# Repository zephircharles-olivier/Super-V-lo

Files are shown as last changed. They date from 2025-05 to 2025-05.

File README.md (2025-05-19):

C’est en combinant passion pour le cyclisme et intérêt pour les systèmes embarqués que j’ai imaginé le Super Vélo : un projet de fin d’année visant à transformer un vélo traditionnel en un moyen de transport intelligent, pratique et connecté.

Le Super Vélo, comme son nom l’indique, regroupe une série d’améliorations techniques soigneusement intégrées. Éclairage avant, feux de signalisation, et collecte de données en temps réel ne sont que quelques-unes des fonctionnalités que j’ai développées pour améliorer la sécurité et l’expérience utilisateur. Grâce à une connexion Internet, les données de vitesse et de fréquence cardiaque sont transmises sur une base de données et consultables directement sur un téléphone cellulaire.

Vous pouvez trouvez içi le code source, les schémas électroniques, les fichiers Gerbers et les fichiers de conception

Voir le projet sur mon site Web: https://tgemaisonneuve.com/wp-admin/post.php?post=1706&action=edit

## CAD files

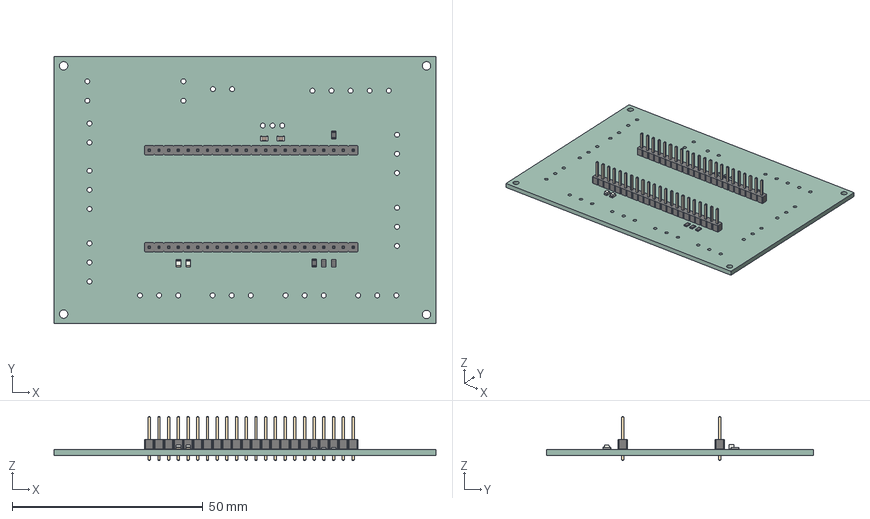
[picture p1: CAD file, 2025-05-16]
Controleur/pcbmaster/pcbmaster/pcbmaster.step
100.0 x 70.0 x 11.5 mm
LED_0805_2012Metric x 2
PinHeader_1x22_P254mm_Vertical x 2
C_0805_2012Metric x 2
R_0805_2012Metric x 4
pcbmaster_PCB

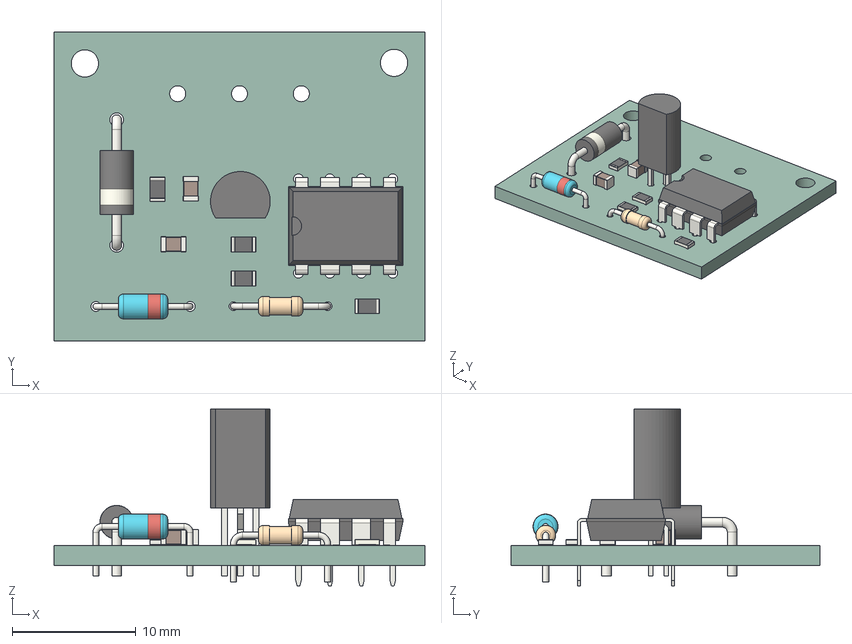
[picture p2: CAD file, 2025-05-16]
Hall_PCB/pcb3/pcb3.step
30.0 x 25.0 x 14.3 mm
R_Axial_DIN0204_L36mm_D16mm_P762mm_Horizontal
D_DO-35_SOD27_P7.62mm_Horizontal
D_DO-41_SOD81_P10.16mm_Horizontal
TO-92L_Narrow
DIP-8_W7.62mm
R_0805_2012Metric x 4
C_0805_2012Metric x 2
pcb3_PCB

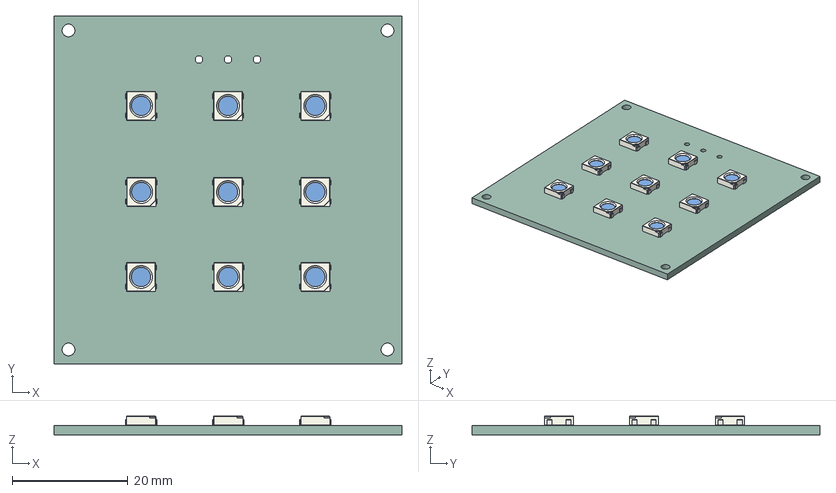
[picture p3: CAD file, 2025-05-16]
Panneaux_LEDs_PCB/pcb2/pcb2.step
60.0 x 60.0 x 3.25 mm
LED_WS2812B_PLCC4_50x50mm_P32mm x 9
pcb2_PCB

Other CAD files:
Boitiers et Assemblage/Magnet1 v28.f3z
Boitiers et Assemblage/PCBMaster Boitier.f3z
Boitiers et Assemblage/Phare Avant.f3z
Boitiers et Assemblage/Phares Arriere.f3z
Boitiers et Assemblage/Switch Boitier.f3d
Panneaux_LEDs_PCB/pcb2/pcb2 Copy v1.f3d

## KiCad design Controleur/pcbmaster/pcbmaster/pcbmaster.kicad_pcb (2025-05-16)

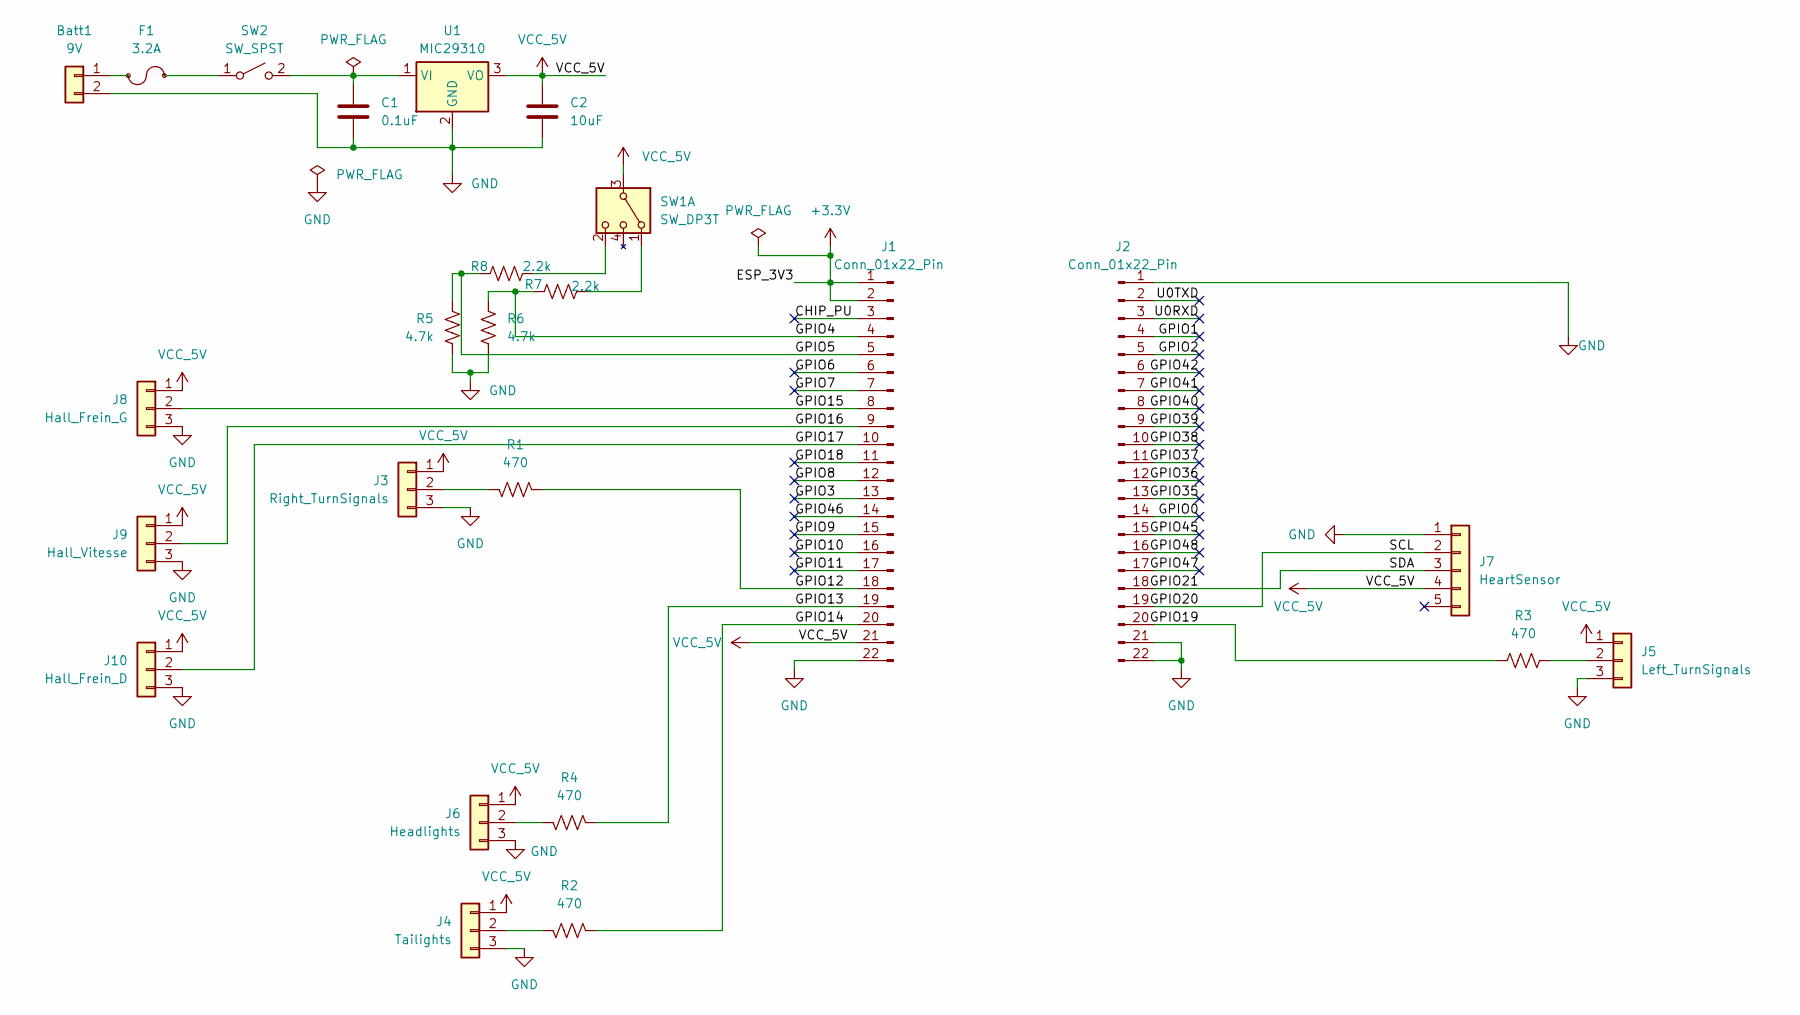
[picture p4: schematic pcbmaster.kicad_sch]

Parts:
Batt1: 9V; 691137710002
C1: 0.1uF; C_0805_2012Metric_Pad1.18x1.45mm_HandSolder
C2: 10uF; C_0805_2012Metric_Pad1.18x1.45mm_HandSolder
F1: 3.2A; FUSE_3519
J1, J2: Conn_01x22_Pin; PinHeader_1x22_P2.54mm_Vertical
J3: Right_TurnSignals; CONN_3pos_GREEN
J4: Tailights; CONN_3pos_GREEN
J5: Left_TurnSignals; CONN_3pos_GREEN
J6: Headlights; CONN_3pos_GREEN
J7: HeartSensor; CONN_5_pos_GREEN
J8: Hall_Frein_G; CONN_3pos_GREEN
J9: Hall_Vitesse; CONN_3pos_GREEN
J10: Hall_Frein_D; CONN_3pos_GREEN
R1, R2, R3, R4: 470; R_0805_2012Metric_Pad1.20x1.40mm_HandSolder
R5, R6: 4.7k; LED_0805_2012Metric_Pad1.15x1.40mm_HandSolder
R7, R8: 2.2k; LED_0805_2012Metric_Pad1.15x1.40mm_HandSolder
SW1: SW_DP3T; CONN_3pos_GREEN
SW2: SW_SPST; 691137710002
U1: MIC29310; TO-220-3_MCL

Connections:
+3.3V: J1.1, J1.2
/CHIP_PU: J1.3
/GPIO0: J2.14
/GPIO1: J2.4
/GPIO2: J2.5
/GPIO3: J1.13
/GPIO4: J1.4, R6.2, R7.1, R7.2, SW1.1 (IO1)
/GPIO5: J1.5, R5.2, R8.1, R8.2, SW1.2 (IO2)
/GPIO6: J1.6
/GPIO7: J1.7
/GPIO8: J1.12
/GPIO9: J1.15
/GPIO10: J1.16
/GPIO11: J1.17
/GPIO12: J1.18, R1.1
/GPIO13: J1.19, R4.1
/GPIO14: J1.20, R2.1
/GPIO15: J1.8, J8.2
/GPIO16: J1.9, J9.2
/GPIO17: J1.10, J10.2
/GPIO18: J1.11
/GPIO19: J2.20, R3.1
/GPIO20: J2.19, J7.2
/GPIO21: J2.18, J7.3
/GPIO35: J2.13
/GPIO36: J2.12
/GPIO37: J2.11
/GPIO38: J2.10
/GPIO39: J2.9
/GPIO40: J2.8
/GPIO41: J2.7
/GPIO42: J2.6
/GPIO45: J2.15
/GPIO46: J1.14
/GPIO47: J2.17
/GPIO48: J2.16
/U0RXD: J2.3
/U0TXD: J2.2
GND: Batt1.2, C1.2, C2.2, J1.22, J2.1, J2.21, J2.22, J3.3, J4.3, J5.3, J6.3, J7.1, J8.3, J9.3, J10.3, R5.1, R6.1, U1.2 (GND)
unnamed: Batt1.1, F1.1
unnamed: J3.2, R1.2
unnamed: J4.2, R2.2
unnamed: J5.2, R3.2
unnamed: J6.2, R4.2
unnamed: F1.2, SW2.1 (A)
unnamed: C1.1, SW2.2 (B), U1.1 (VI)
VCC_5V: C2.1, J1.21, J3.1, J4.1, J5.1, J6.1, J7.4, J8.1, J9.1, J10.1, SW1.3 (VCC), U1.3 (VO)

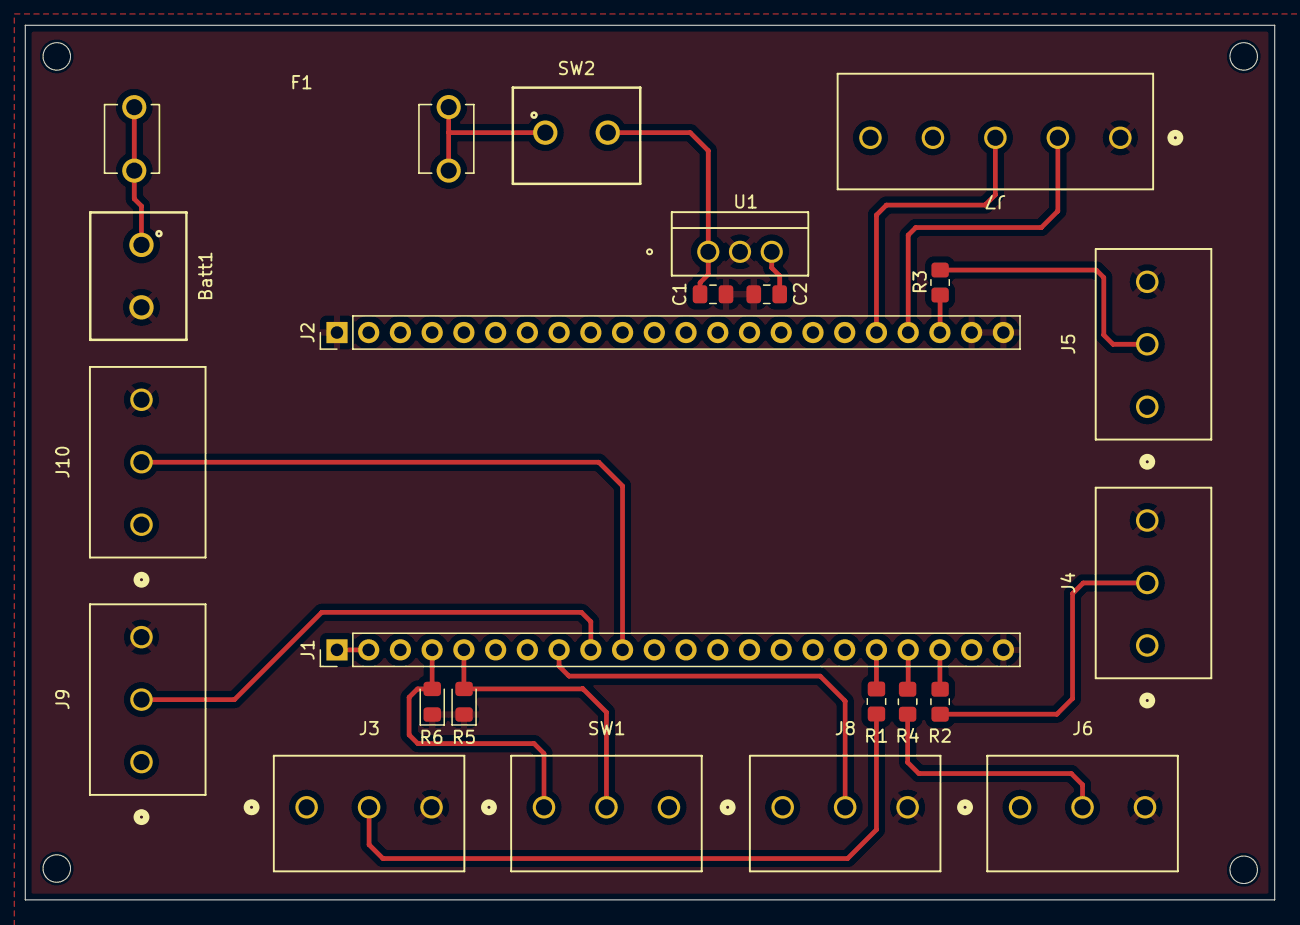
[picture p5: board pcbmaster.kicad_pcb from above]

Board: 2 copper layers, 100.0 x 70.0 mm, 23 parts (0 on the bottom side), 21 nets.

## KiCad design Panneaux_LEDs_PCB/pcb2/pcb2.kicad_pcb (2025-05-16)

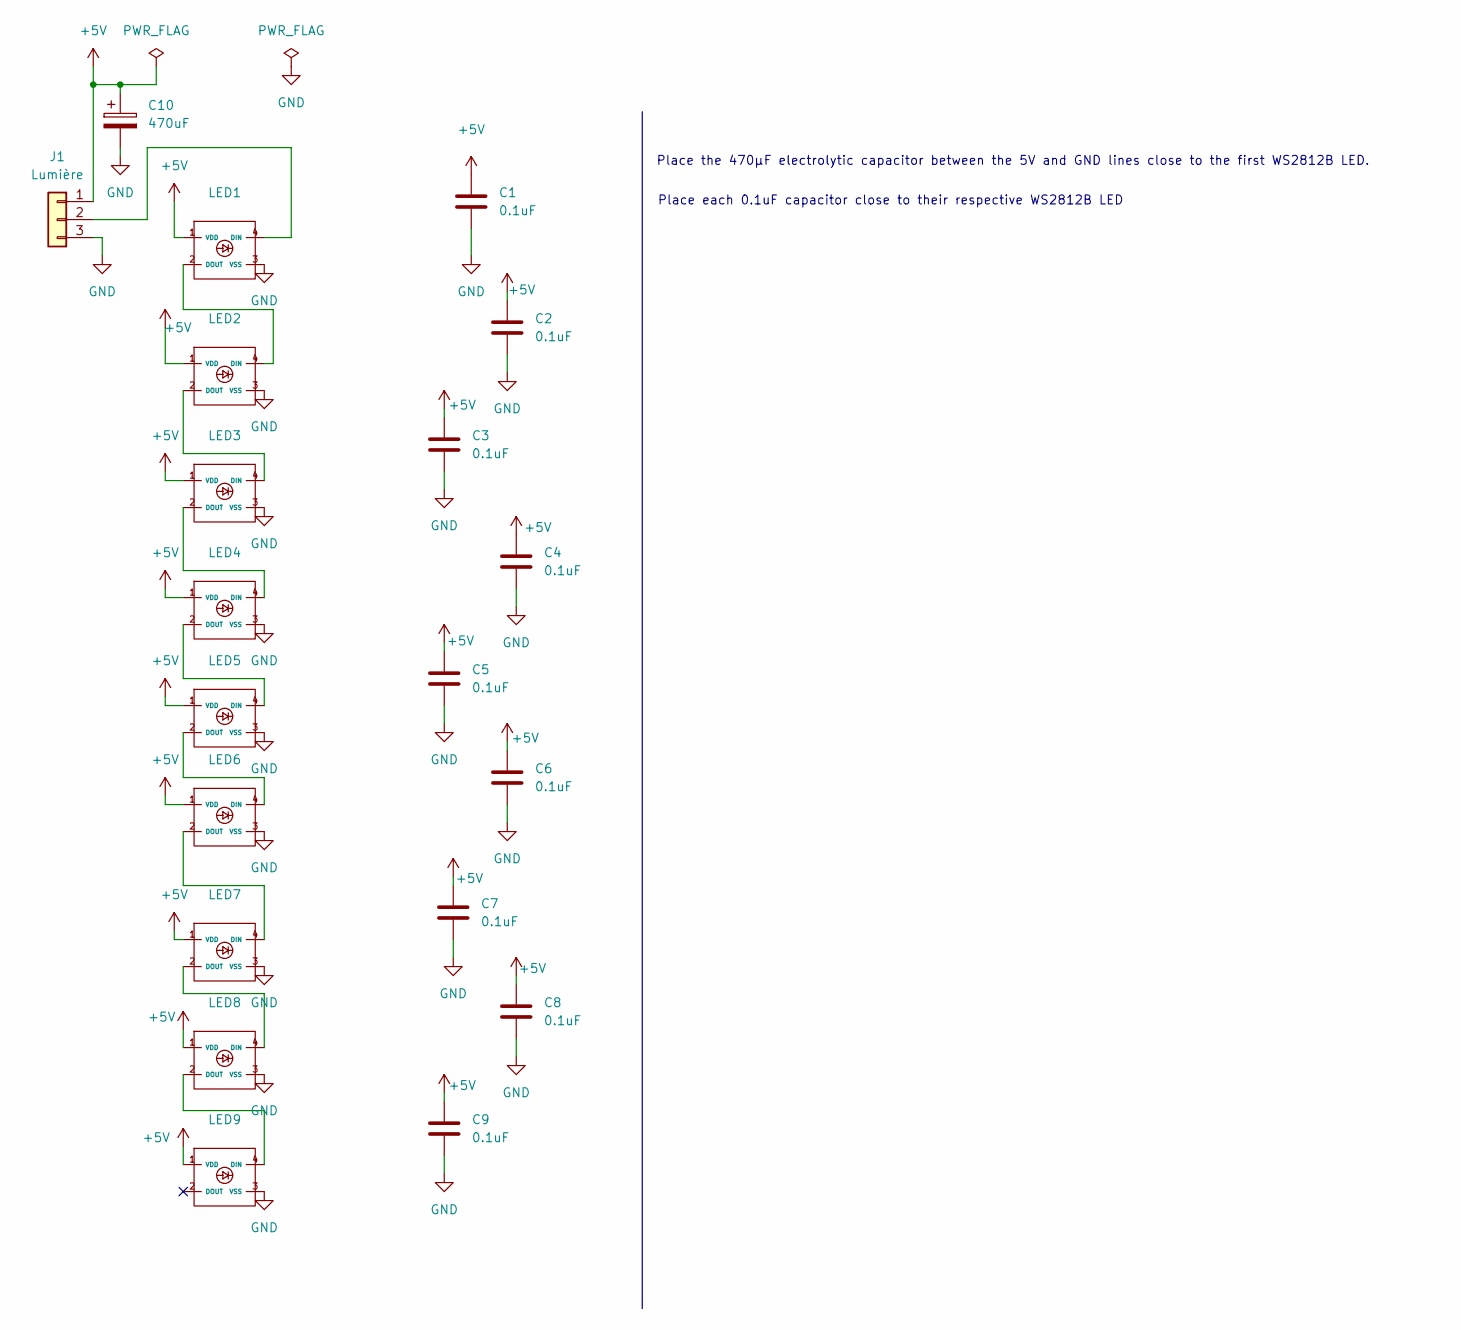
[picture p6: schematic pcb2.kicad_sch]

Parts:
C1, C2, C3, C4, C5, C6, C7, C8, C9: 0.1uF; C_size0805
C10: 470uF; PCAP_8x10-ELECT_NCA
J1: Lumière; CONN_3pos_GREEN
LED1, LED2, LED3, LED4, LED5, LED6, LED7, LED8, LED9: LED_WS2812B_PLCC4_5.0x5.0mm_P3.2mm

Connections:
+5V: C1.1, C2.1, C3.1, C4.1, C5.1, C6.1, C7.1, C8.1, C9.1, C10.1, J1.1, LED1.1 (VDD), LED2.1 (VDD), LED3.1 (VDD), LED4.1 (VDD), LED5.1 (VDD), LED6.1 (VDD), LED7.1 (VDD), LED8.1 (VDD), LED9.1 (VDD)
GND: C1.2, C2.2, C3.2, C4.2, C5.2, C6.2, C7.2, C8.2, C9.2, C10.2, J1.3, LED1.3 (VSS), LED2.3 (VSS), LED3.3 (VSS), LED4.3 (VSS), LED5.3 (VSS), LED6.3 (VSS), LED7.3 (VSS), LED8.3 (VSS), LED9.3 (VSS)
unnamed: J1.2, LED1.4 (DIN)
unnamed: LED1.2 (DOUT), LED2.4 (DIN)
unnamed: LED2.2 (DOUT), LED3.4 (DIN)
unnamed: LED3.2 (DOUT), LED4.4 (DIN)
unnamed: LED4.2 (DOUT), LED5.4 (DIN)
unnamed: LED5.2 (DOUT), LED6.4 (DIN)
unnamed: LED6.2 (DOUT), LED7.4 (DIN)
unnamed: LED7.2 (DOUT), LED8.4 (DIN)
unnamed: LED8.2 (DOUT), LED9.4 (DIN)

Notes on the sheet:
Place each 0.1uF capacitor close to their respective WS2812B LED
Place the 470µF electrolytic capacitor between the 5V and GND lines close to the first WS2812B LED.

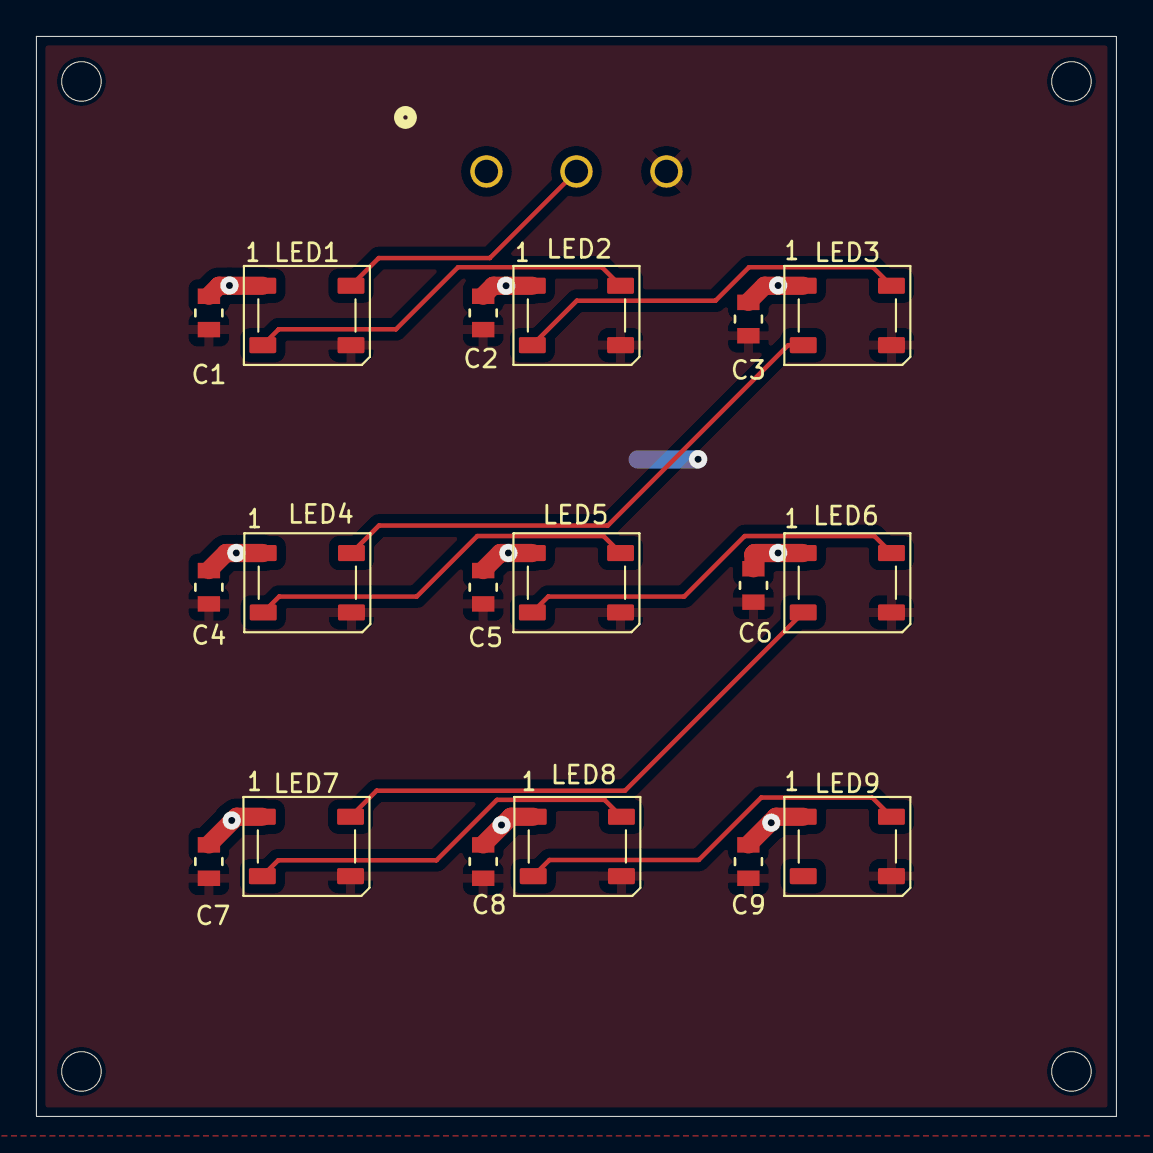
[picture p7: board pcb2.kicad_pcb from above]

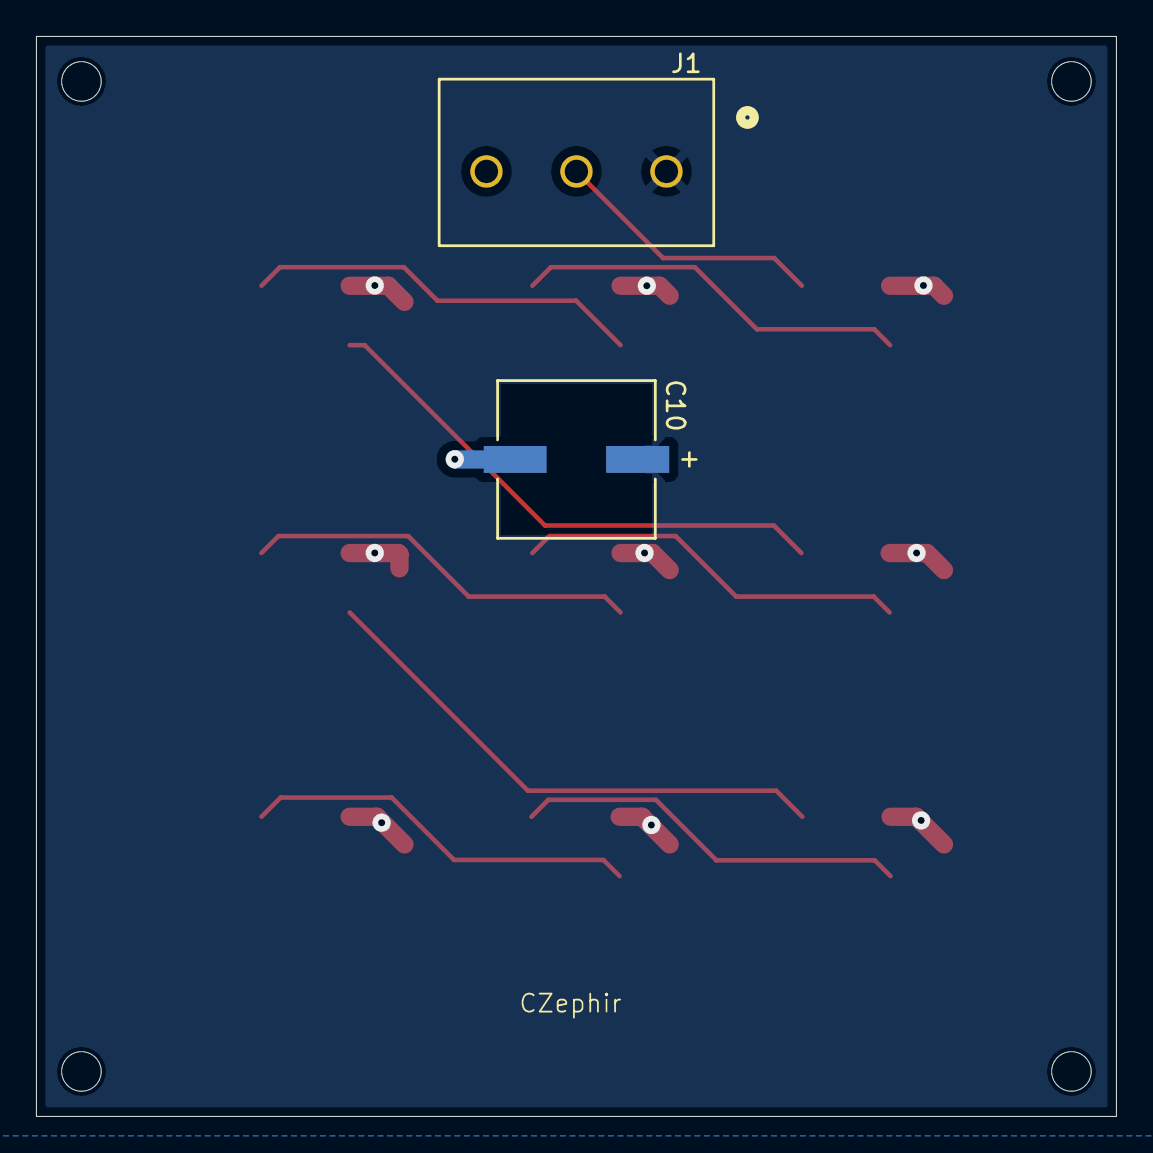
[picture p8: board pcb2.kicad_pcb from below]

Board: 2 copper layers, 60.0 x 60.0 mm, 20 parts (2 on the bottom side), 11 nets.

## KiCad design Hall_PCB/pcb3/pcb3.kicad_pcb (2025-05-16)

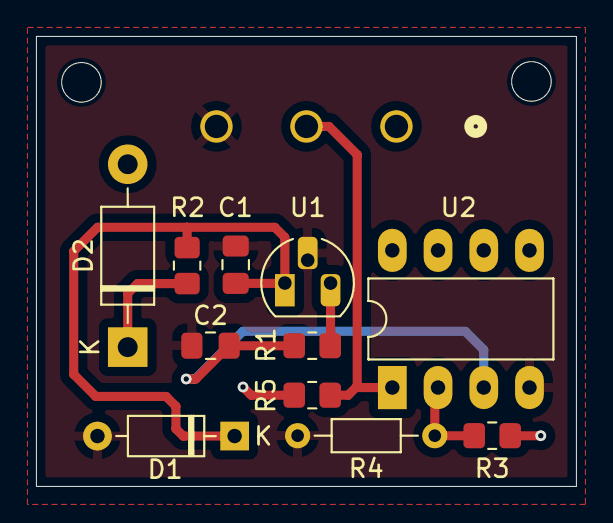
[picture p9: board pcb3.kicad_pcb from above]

Board: 2 copper layers, 30.0 x 25.0 mm, 12 parts (1 on the bottom side), 8 nets.

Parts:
C1: 100nF; C_0805_2012Metric_Pad1.18x1.45mm_HandSolder
C2: 4.7nF; C_0805_2012Metric_Pad1.18x1.45mm_HandSolder
D1: D_Zener; D_DO-35_SOD27_P7.62mm_Horizontal
D2: 1N4004-TP; D_DO-41_SOD81_P10.16mm_Horizontal
J1: Hall_Vitesse; CONN_3pos_GREEN
R1, R3, R5: 10k; R_0805_2012Metric_Pad1.20x1.40mm_HandSolder
R2: 100; R_0805_2012Metric_Pad1.20x1.40mm_HandSolder
R4: 500; R_Axial_DIN0204_L3.6mm_D1.6mm_P7.62mm_Horizontal
U1: US5881; TO-92L_HandSolder
U2: LM393; DIP-8_W7.62mm_LongPads

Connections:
+5V: D2.2 (A), J1.1, R3.1, R5.1, U2.8 (V+)
/OUT_5V: J1.2, R5.2, U2.1
GND: C1.2, C2.1, D1.2 (A), J1.3, R4.2, U1.2 (GND), U2.4 (V-)
unnamed: C1.1, D1.1 (K), R2.2, U1.1 (VDD)
unnamed: D2.1 (K), R2.1
unnamed: R1.1, U1.3 (OUT)
unnamed: C2.2, R1.2, U2.3 (+)
unnamed: R3.2, R4.1, U2.2 (-)

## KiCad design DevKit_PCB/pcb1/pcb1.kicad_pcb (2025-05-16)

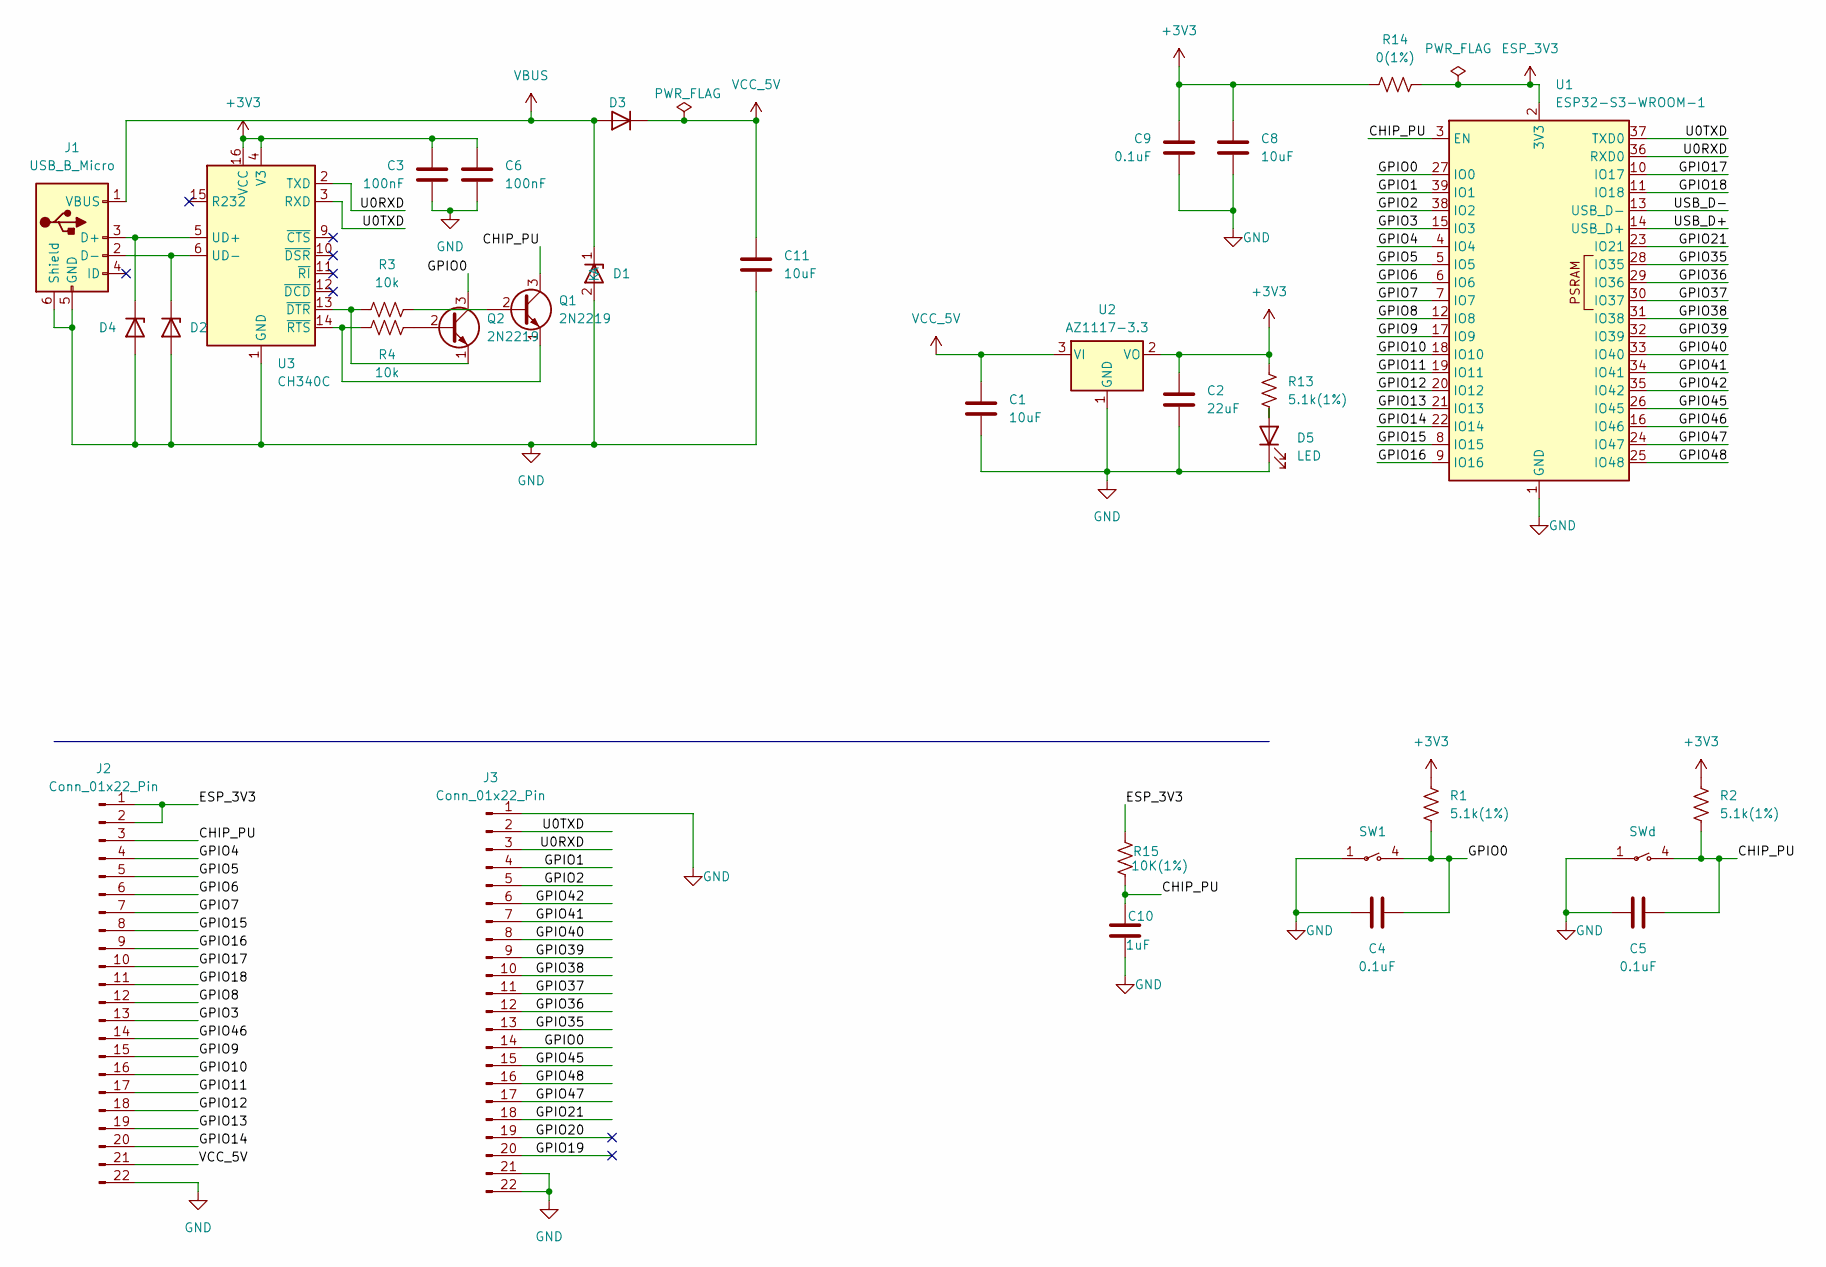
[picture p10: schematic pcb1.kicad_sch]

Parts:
C1, C11: 10uF; C_10uF
C2: 22uF; C_size0805
C3, C6: 100nF; C_size0805
C4, C5, C9: 0.1uF; C_0805_2012Metric
C8: 10uF; C_size0805
C10: 1uF; C_0805_2012Metric
D1, D2, D4: SMA6J58CA-Q; CR_041-1JY_STM
D3: Schottky
D5: LED; LED_R
J1: USB_B_Micro; USB2.0(10118193)
J2, J3: Conn_01x22_Pin; PinHeader_1x22_P2.54mm_Vertical
Q1, Q2: 2N2219; BSR14
R1, R2, R13: 5.1k(1%); R_0805_2012Metric
R3, R4: 10k; R_10k(1%)
R14: 0(1%); R_0
R15: 10K(1%); R_10k(1%)
SW1: PTS 647 SN50 SMTR2 LFS
SWd: PTS 647 SN50 SMTR2 LFS
U1: ESP32-S3-WROOM-1
U2: AZ1117-3.3; SOT-223-3_TabPin2
U3: CH340C; SOIC-16_3.9x9.9mm_P1.27mm

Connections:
+3V3: C2.1, C3.1, C6.1, C8.1, C9.1, R1.2, R2.2, R13.2, R14.1, U2.2 (VO), U3.4 (V3), U3.16 (VCC)
/CHIP_PU: C5.2, C10.1, J2.3, Q1.3 (C), R2.1, R15.2, SWd.4, U1.3 (EN); also elsewhere on the board
/GPIO0: C4.2, J3.14, Q2.3 (C), R1.1, SW1.4, U1.27 (IO0)
/GPIO1: J3.4, U1.39 (IO1)
/GPIO2: J3.5, U1.38 (IO2)
/GPIO3: J2.13, U1.15 (IO3)
/GPIO4: J2.4, U1.4 (IO4)
/GPIO5: J2.5, U1.5 (IO5)
/GPIO6: J2.6, U1.6 (IO6)
/GPIO7: J2.7, U1.7 (IO7)
/GPIO8: J2.12, U1.12 (IO8)
/GPIO9: J2.15, U1.17 (IO9)
/GPIO10: J2.16, U1.18 (IO10)
/GPIO11: J2.17, U1.19 (IO11)
/GPIO12: J2.18, U1.20 (IO12)
/GPIO13: J2.19, U1.21 (IO13)
/GPIO14: J2.20, U1.22 (IO14)
/GPIO15: J2.8, U1.8 (IO15)
/GPIO16: J2.9, U1.9 (IO16)
/GPIO17: J2.10, U1.10 (IO17)
/GPIO18: J2.11, U1.11 (IO18)
/GPIO19: J3.20
/GPIO20: J3.19
/GPIO21: J3.18, U1.23 (IO21)
/GPIO35: J3.13, U1.28 (IO35)
/GPIO36: J3.12, U1.29 (IO36)
/GPIO37: J3.11, U1.30 (IO37)
/GPIO38: J3.10, U1.31 (IO38)
/GPIO39: J3.9, U1.32 (IO39)
/GPIO40: J3.8, U1.33 (IO40)
/GPIO41: J3.7, U1.34 (IO41)
/GPIO42: J3.6, U1.35 (IO42)
/GPIO45: J3.15, U1.26 (IO45)
/GPIO46: J2.14, U1.16 (IO46)
/GPIO47: J3.17, U1.24 (IO47)
/GPIO48: J3.16, U1.25 (IO48)
/U0RXD: J3.3, U1.36 (RXD0), U3.2 (TXD)
/U0TXD: J3.2, U1.37 (TXD0), U3.3 (RXD)
/USB_D+: U1.14 (USB_D+)
/USB_D-: U1.13 (USB_D-)
ESP_3V3: J2.1, J2.2, R14.2, R15.1, U1.2 (3V3)
GND: C1.2, C2.2, C3.2, C4.1, C5.1, C6.2, C8.2, C9.2, C10.2, C11.2, D1.2 (A), D2.2 (A), D4.2 (A), D5.1 (K), J1.5 (GND), J1.6 (Shield), J2.22, J3.1, J3.21, J3.22, SW1.1, SWd.1, U1.1 (GND), U1.40 (GND), U1.41 (GND), U2.1 (GND), U3.1 (GND); also elsewhere on the board
unnamed: D2.1 (K), J1.2 (D-), U3.6 (UD-)
unnamed: D4.1 (K), J1.3 (D+), U3.5 (UD+)
unnamed: D5.2 (A), R13.1
unnamed: Q1.2 (B), R3.2
unnamed: Q1.1 (E), R4.1, U3.14 (~RTS)
unnamed: Q2.2 (B), R4.2
unnamed: Q2.1 (E), R3.1, U3.13 (~DTR)
VBUS: D1.1 (K), D3.2 (A), J1.1 (VBUS)
VCC_5V: C1.1, C11.1, D3.1 (K), J2.21, U2.3 (VI)

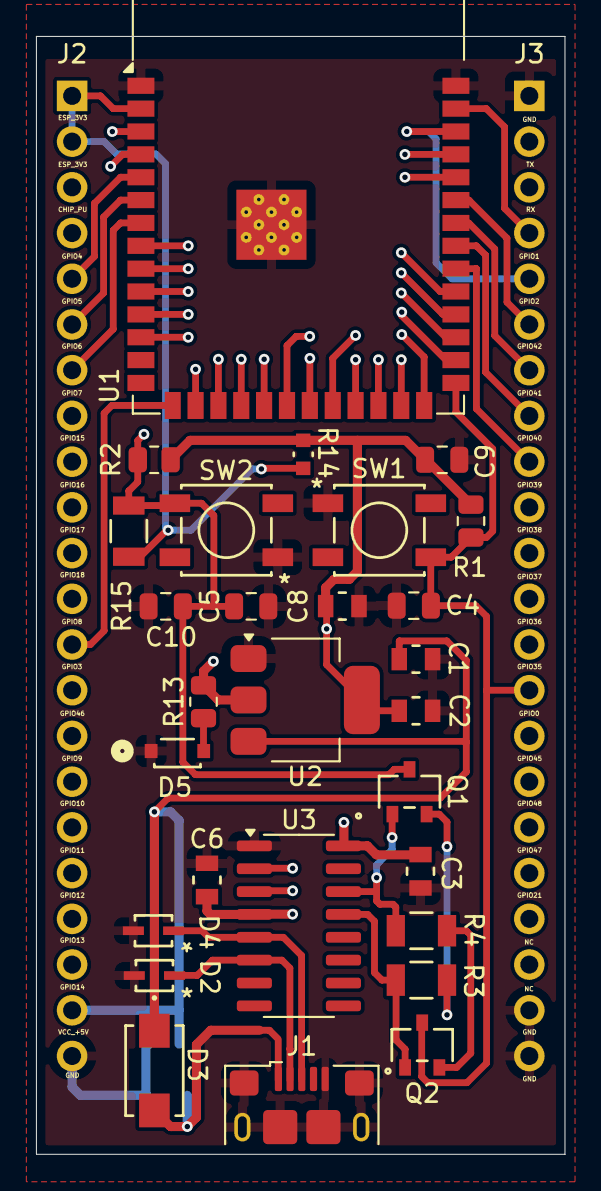
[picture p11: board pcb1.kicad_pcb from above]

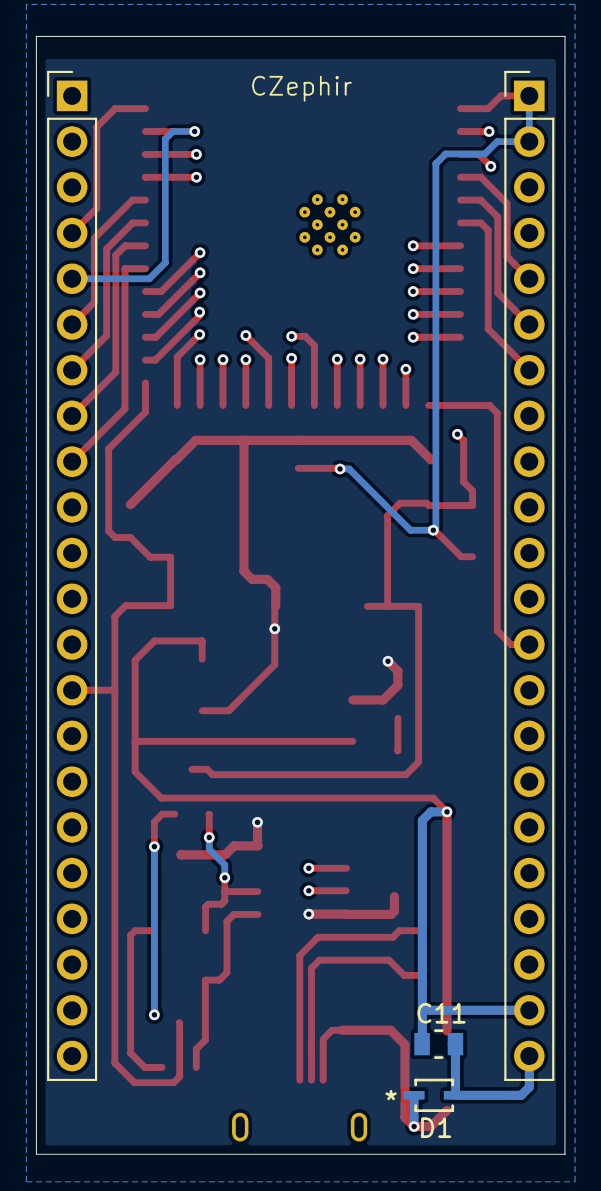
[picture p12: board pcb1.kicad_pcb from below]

Board: 4 copper layers, 29.4 x 62.1 mm, 32 parts (4 on the bottom side), 47 nets.

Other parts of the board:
SW2: PTS 647 SN50 SMTR2 LFS

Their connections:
/CHIP_PU: SW2.4; also elsewhere on the board
GND: SW2.1; also elsewhere on the board

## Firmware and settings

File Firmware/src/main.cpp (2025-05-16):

#include <stdint.h>
#include <Arduino.h>

#include <LED_Animations.h>
#include <WifiMQTT.h>
#include <HeartrateDetection.h>

//---------Heartrate Pin--------//
#define VIBRATION_PIN 14//J4
// -----------------------------
// Switch Pins
// -----------------------------
#define LEFT_SWITCH_PIN 4 //SW1
#define RIGHT_SWITCH_PIN 5//SW1

// -----------------------------
// Hall Sensor Pin
// -----------------------------
#define HALL_SENSOR_PIN 47    //J5
//#define HALL_SENSOR_PIN2 15 //J8

// -----------------------------
// Speed Sensor Setup
// -----------------------------
#define SPEED_SENSOR_PIN 16 //J9
#define MIN_VALID_INTERVAL 170    // Reject anything faster than 170 ms (limit of speed at 47 km/h)
#define WHEEL_CIRCUMFERENCE_M 2.2 // 27.5" wheel

volatile unsigned long lastEdgeTime = 0;
volatile unsigned long interval = 0;
volatile bool edgeDetected = false;
float speed = 0.0;
unsigned long lastEdgeTimeCopy = 0;
bool speedWasZero = false;

/*action modulation*/
unsigned long lastActionTime = 0;
const unsigned long actionInterval = 200; // 200 ms
//timer for speed actualization//
unsigned long lastZeroSpeedSent = 0;  // tracks when speed=0 was last published
const unsigned long zeroSpeedCooldown = 5000;  // only publish once every 5s
// -----------------------------
// LED Animation Based on Switch
// -----------------------------
void updateFrontPanelWithHallSensor()
{
  frontStrip.clear();
  for (int i = 0; i < LED_COUNT; i++)
  {
    if (i == 4)
    {
      if (digitalRead(HALL_SENSOR_PIN) == LOW)
        frontStrip.setPixelColor(i, redFront);
      else
        frontStrip.setPixelColor(i, whiteFront);
    }
    else
    {
      frontStrip.setPixelColor(i, whiteFront);
    }
  }
  frontStrip.show();
}

void updateBackPanel()
{
  bool hallActive = (digitalRead(HALL_SENSOR_PIN) == LOW);
  uint32_t color = hallActive ? redBackBright : redBackDim;
  for (int i = 0; i < LED_COUNT; i++)
  {
    backStrip.setPixelColor(i, color);
  }
  backStrip.show();
}
//interrupt for speed
void IRAM_ATTR handleFallingEdge()
{
  if (digitalRead(SPEED_SENSOR_PIN) == LOW)
  {
    unsigned long currentTime = millis();
    unsigned long newInterval = currentTime - lastEdgeTime;

    if (newInterval >= MIN_VALID_INTERVAL)
    {
      interval = newInterval;
      edgeDetected = true;
      lastEdgeTime = currentTime;
    }
  }
}
// -----------------------------
// Setup and Loop
// -----------------------------
void setup()
{


  Serial.begin(115200);
  pinMode(VIBRATION_PIN, INPUT);
  pinMode(LEFT_SWITCH_PIN, INPUT);
  pinMode(RIGHT_SWITCH_PIN, INPUT);
  pinMode(HALL_SENSOR_PIN, INPUT);
  pinMode(SPEED_SENSOR_PIN, INPUT_PULLUP);
  attachInterrupt(digitalPinToInterrupt(SPEED_SENSOR_PIN), handleFallingEdge, FALLING);

  leftStrip.begin();
  rightStrip.begin();
  frontStrip.begin();
  backStrip.begin();

  leftStrip.fill(leftStrip.Color(0, 255, 0));
  leftStrip.show();
  delay(2000);
  leftStrip.clear();
  leftStrip.show();

  rightStrip.fill(rightStrip.Color(0, 255, 0));
  rightStrip.show();
  delay(2000);
  rightStrip.clear();
  rightStrip.show();

  frontStrip.clear();
  frontStrip.show();

  backStrip.clear();
  backStrip.show();

  setup_wifi();
  client.setServer(mqtt_server, 1883);
  client.setCallback(callback);
  Serial.println("Ready to detect BPM and animate LEDs...");
}

void loop()
{
  noInterrupts();
  lastEdgeTimeCopy = lastEdgeTime; // Safely copy for use outside ISR
  unsigned long now = millis();
  unsigned long timeBetweenEdges = interval;
  edgeDetected = false;
  interrupts();
  if (online)
  {
    if (!client.connected())
    {
      reconnect();
    }
    client.loop();
  }
// -----------------------------------------------------
// Actions And manipulations with LED Panels  
// -----------------------------------------------------
unsigned long currentMillis = millis();
  if (currentMillis - lastActionTime >= actionInterval)
  {
    lastActionTime = currentMillis;
    processHeartRate();
    handleLEDAnimations();
    updateFrontPanelWithHallSensor();
    updateBackPanel();
  }
//-----------------------------------------------------
// Update speed back to zero                    
//-----------------------------------------------------

  if (now - lastEdgeTimeCopy > 10000)
  {
    if (now - lastZeroSpeedSent >= zeroSpeedCooldown)
    {
      //Setting the speed to 0
      speed = 0;
      Serial.print("Speed: ");
      Serial.print(speed, 1);
      Serial.println(" km/h");
      
      
      //Sending to the internet
      char speedMsg[16];
      sprintf(speedMsg, "%.1f km/h", speed);
      client.publish("esp32/rpm", speedMsg);
      Serial.print("published:");
      Serial.println(speedMsg);
      
      lastZeroSpeedSent = now;  // Reset cooldown timer
    }
  }
//-----------------------------------------------------
// Detect a full revolution                       
//-----------------------------------------------------
  if (edgeDetected)
  {

    float speed = 0.0;
    if (timeBetweenEdges > 0)
    {
      speed = (WHEEL_CIRCUMFERENCE_M * 1000.0) / timeBetweenEdges * 3.6; //conversion of m/s accomplished into km/h
    }
    Serial.print("⏱ Time between falling edges: ");
    Serial.print(timeBetweenEdges);
    Serial.println(" ms");
    Serial.print("Speed: ");
    Serial.print(speed, 1);
    Serial.println(" km/h");
    //Upload it to the internet
    if (online){
      char speedMsg[16];
      sprintf(speedMsg, "%.1f km/h", speed);
      client.publish("esp32/rpm", speedMsg);
      Serial.print("published:");
      Serial.println(speedMsg);
    }
  }
}

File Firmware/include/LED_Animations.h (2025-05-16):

#ifndef LED_ANIMATIONS_H
#define LED_ANIMATIONS_H

#include <Adafruit_NeoPixel.h>

// -----------------------------
// LED Panel Setup
// -----------------------------
#define LED_COUNT 9 
#define LEFT_LED_PIN 21 //J7 #3
#define RIGHT_LED_PIN 12 //J3
#define FRONT_LED_PIN 13 //J6
#define BACK_LED_PIN 17 //J10

extern Adafruit_NeoPixel leftStrip;
extern Adafruit_NeoPixel rightStrip;
extern Adafruit_NeoPixel frontStrip;
extern Adafruit_NeoPixel backStrip;

extern uint32_t yellowleft;
extern uint32_t yellowright;
extern uint32_t whiteFront;
extern uint32_t redFront;
extern uint32_t redBackDim;
extern uint32_t redBackBright;

void clearStrips();
void handleLEDAnimations();
void updateBackPanel();
void TurnLeft1(Adafruit_NeoPixel &strip);
void TurnRight1(Adafruit_NeoPixel &strip);

#endif
